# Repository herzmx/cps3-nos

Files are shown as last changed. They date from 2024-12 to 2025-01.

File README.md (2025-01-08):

# CPS3 NOS (NOR Open SIMM)

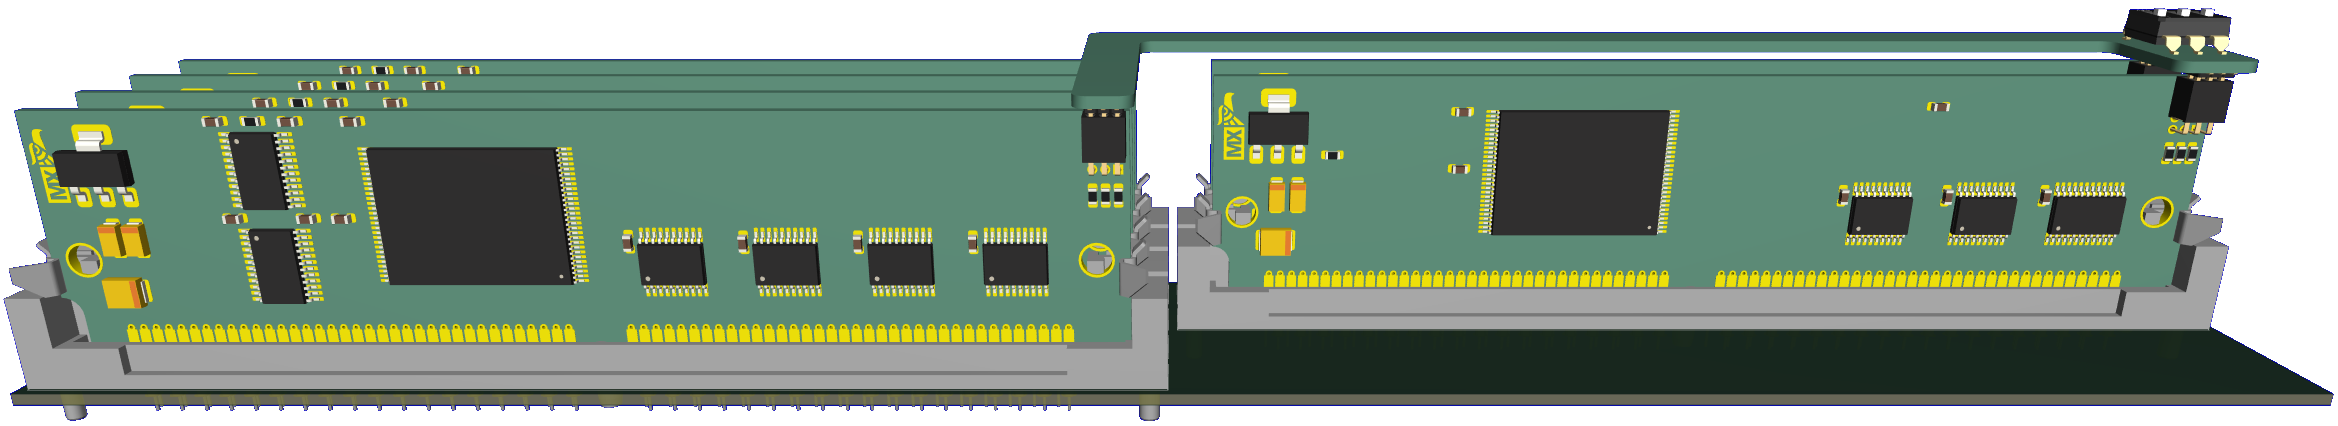
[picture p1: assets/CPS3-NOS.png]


CPS3 NOS is an alternative to the original SIMMs for CPS3; currently, the available options include clone SIMMs with old-stock FLASH memory and Ultra SIMMs by DS. 

The project shares similarities with UltraSIMM but is not based on it. Instead, it is a new implementation built using publicly available pinouts and CPS3 schematics from FPGA projects.

The initial design aimed to use SPANSION NOR FLASH as the main memory, but this proved unfeasible due to speed limitations causing significant instability. As a result, MICRON NOR FLASH was used instead. While this is the same type of memory used in UltraSIMM and shares its pinout, but it's not directly compatible with UltraSIMM/UltraBIOS setup, because it is an entirely separate implementation.

The primary purpose of this project is to provide an alternative to SIMMs for catridges with original keys and battery, addressing the risks involved when updating the BIOS using the [CPS3 SIMM/CARTRIDGE PORT ADAPTER for OSCR](https://github.com/herzmx/CPS3-OSCR-Adapter). This project is not intended to create a new multi-SIMM solution. Given this primary purpose, it is very likely that UltraSIMM would also works on catridges with original keys and battery, though I do not have access to one to confirm.

## Issue Detected on 128MB NOS Module

Issue is identified with the 128MB NOS module causing intermittent problems after extended use. This may impact performance in games.

If you’ve already sent files for a production release, we sincerely apologize for the inconvenience. At this time, I’m not entirely confident in the stability of this release.

The primary purpose of this project is extend the functionality of [CPS3 SIMM/CARTRIDGE PORT ADAPTER for OSCR](https://github.com/herzmx/CPS3-OSCR-Adapter). With this adapter, you gain exciting new possibilities for dumping cartridges or testing configurations.

Thank you for your understanding, and I apologize for any inconvenience this may have caused.

<video src="./assets/NOS-128-issue.mp4" width="320" height="240" controls></video>

## Assembly/Production  

Gerber, BOM, and POS files are provided in the `hw` directory. You can send them directly to a PCB fabrication company or assemble the boards yourself.  

When assembling, consider that the minimum pitch is **0.5mm**, and the footprint for capacitors and resistors is **0603**.

**Important!!!**, PCB tickness it's **1.2mm**

### 64MB SIMM  

For 64MB SIMMs, you can use the following parallel NOR FLASH memory chips:  

- **Micron MT28EW256/512/01G**  
- **Spansion S29256/512/GL01G** (use the 100ns speed version)  

### 128MB SIMM  

For 128MB SIMMs, only **Micron MT28EW01G** parallel NOR FLASH is supported. During development and testing, **Spansion** memory did not work as expected with bank switching on the 128MB SIMM.  

### Notes  

- Use only one type of SIMM when assembling a single **64MB SIMM**.  
- You can mix **Micron** and **Spansion** SIMMs if needed.  

## How to use

CPS3 can only handle four types of FLASH memory due to the instructions used for flashing new games through the system, these instructions are supported and coded in the BIOS.  

To make a new NOR FLASH memory compatible with CPS3, a BIOS patch is required.

### BIOS Patch

The **bios_patch.py** script allows you to apply patches to your current BIOS, adding compatibility for **SPANSION** and **MICRON** NOR FLASH.

For example, if you have a dump of *Street Fighter III 3rd Strike*, you can execute the following command to patch BIOS:

```bash
python bios_patch.py sfiii3_usa.29f400.u2 sfiii3
```

#### Compatibility Table

| Before patch | After patch |
|---|---|
| MXCI | MXCI |
| SHARP/INTEL  | SHARP/INTEL |
| HITACHI | SPANSION |
| MXIC | MICRON NOS/UltraSIMM |

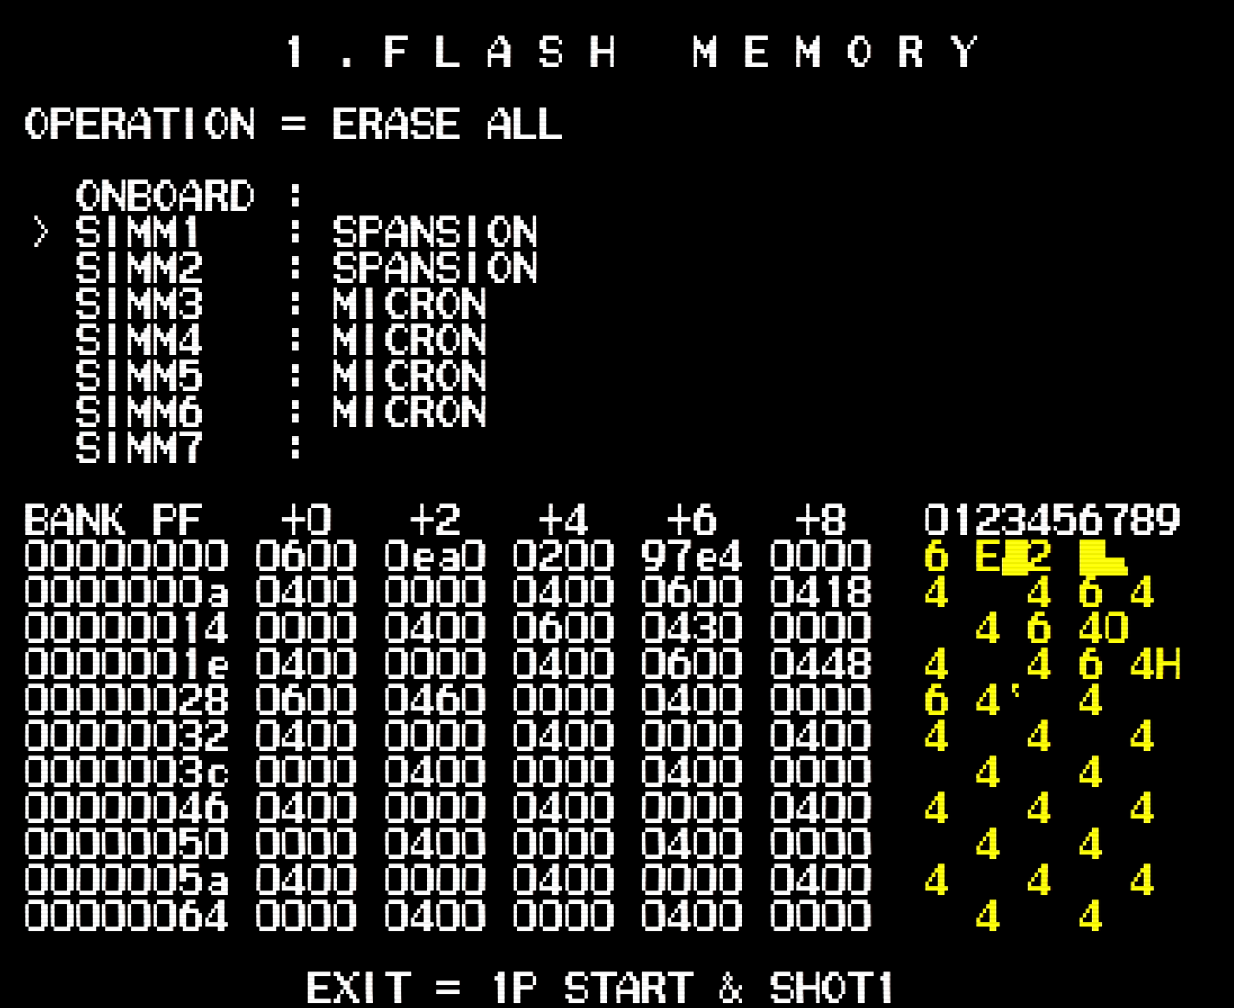
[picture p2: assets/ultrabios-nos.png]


### Flashing Your New BIOS

Once the patch is applied, it's time to flash your updated BIOS onto the cartridge. There are two main methods you can use:

1. **Using the [CPS3 SIMM/CARTRIDGE PORT ADAPTER for OSCR](https://github.com/herzmx/CPS3-OSCR-Adapter)**  
   - This method works for both alive and death cartridges.
   - **NOTE**: Use it at your own risk on alive cartridges!

2. **Traditional Method**  
   - Remove the 29F400 chip from the cartridge and flash it using a programmer.  
   - This method is only recommended for death cartridges.

Now your cartdrige it's compatible with NOS!

### R/W CPS3 NOS 

Currently, CPS3 NOS can only be programmed using the [CPS3 SIMM/CARTRIDGE PORT ADAPTER for OSCR](https://github.com/herzmx/CPS3-OSCR-Adapter).

#### Prepare your files 

- **Dump or copy**  your CD-ROM files and organize them into a directory. For example, for *Street Fighter III: 2nd Impact*, the directory structure should look like this:

	```
    CDROM
    └── SFIII2
        ├── 10
        ├── 20
        ├── 30
        ├── 31
        ├── 40
        ├── 41
        ├── 50
        ├── 51
        ├── 90
        ├── 91
        ├── 92
        └── 93
	```

- Concatenate files for each SIMM
	- For **128M SIMMs**, use files 3# to 6#. 
	- For **64M SIMMs**, use files 10 and 20.
	
	 Example (using a Unix terminal):
	 
	 ```bash
	 	cat WAZARD/10WZ SFIII/10NG SFIII2/10 JOJO/10JO SFIII3B/103S2 JOJOBA/10JB > NOS10

		cat WAZARD/10WZFix SFIII/10NG SFIII2/10 JOJO/10JO SFIII3B/103S2 JOJOBA/10JB > NOS10
		
		cat WAZARD/20WZ SFIII/20NG SFIII2/20 JOJO/20JO SFIII3B/203S2 JOJOBA/20JB > NOS20
		
		cat WAZARD/30WZ WAZARD/31WZ SFIII/30NG SFIII/31NG SFIII2/30 SFIII2/31 JOJO/30JO JOJO/31JO SFIII3B/303S2 SFIII3B/313S2 JOJOBA/30JB JOJOBA/31JB > NOS30
		
		cat WAZARD/40WZ WAZARD/41WZ SFIII/40NG SFIII/41NG SFIII2/40 SFIII2/41 JOJO/40JO JOJO/41JO SFIII3B/403S2 SFIII3B/413S2 JOJOBA/40JB JOJOBA/41JB > NOS40
		
		cat WAZARD/50WZ WAZARD/51WZ SFIII/50NG SFIII/51NG SFIII2/50 SFIII2/51 JOJO/50JO JOJO/51JO SFIII3B/503S2 SFIII3B/513S2 JOJOBA/50JB JOJOBA/51JB > NOS50
		
		cat WAZARD/60WZ WAZARD/61WZ SFIII/60NG SFIII/61NG SFIII2/60 SFIII2/61 JOJO/60JO JOJO/61JO SFIII3B/603S2 SFIII3B/613S2 JOJOBA/60JB JOJOBA/61JB > NOS60
	 ```
	 
**Important Notes**
 
- NOS supports up to 8 titles. When using this feature, you must fill all SIMM slots and space.
- For example, when working with *Street Fighter III: New Generation*, you can duplicate certain files to fill all space:
- Use `10` as `20` for SIMM 2.
- Use `50` four times for SIMM 5.
- Use `40` as `60 `for SIMM 6.
 	
| | 1 | 2 | 3 | 4 | 5 | 6 |
|---|---|---|---|---|---|---|
| Street Fighter III: New Generation | 64MBit | - | 128MBit | 128MBit | 32MBit  | - |
| Street Fighter III: New Generation (filled) | 64MBit | 64MBit | 128MBit | 128MBit | 128MBit | 128MBit |

Alternatively, you can use the **ds2nos.py** script to convert UltraSIMM files to NOS format.

#### Write NOS

The [CPS3 SIMM/CARTRIDGE PORT ADAPTER for OSCR](https://github.com/herzmx/CPS3-OSCR-Adapter) has designated slots for 64M and 128M SIMMs. Insert your NOS into the corresponding slot and connect the headers for additional addressing.

system
system

- Prepare your SD, copy NOS10* to NOS60* in root
- Use *Capcom System III* menu options to write files
- 128 MB

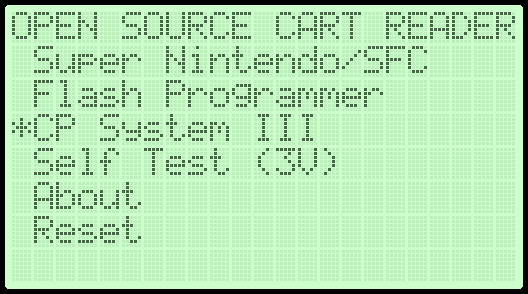
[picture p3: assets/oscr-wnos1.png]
	
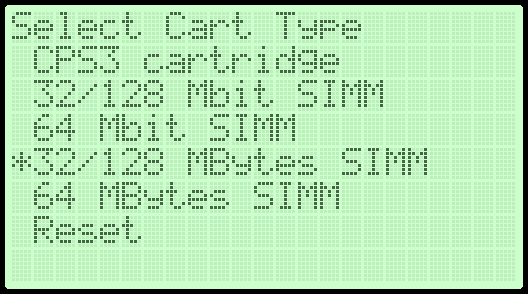
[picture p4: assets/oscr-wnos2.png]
	
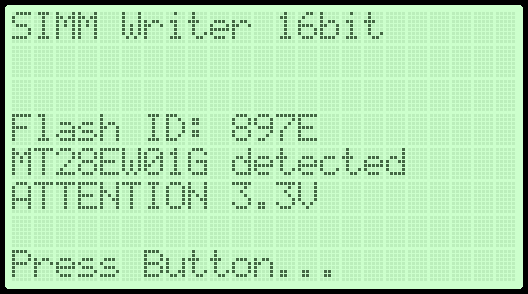
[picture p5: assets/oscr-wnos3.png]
	
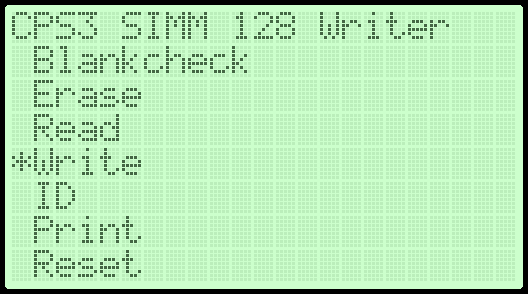
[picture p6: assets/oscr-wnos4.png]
	
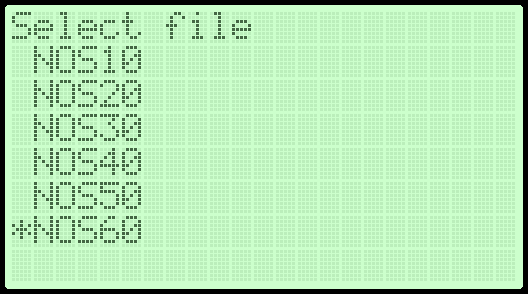
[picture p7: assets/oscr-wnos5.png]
	
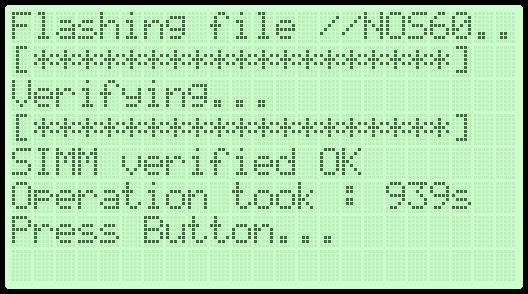
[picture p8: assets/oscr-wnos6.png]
	

- 64 MB

	system
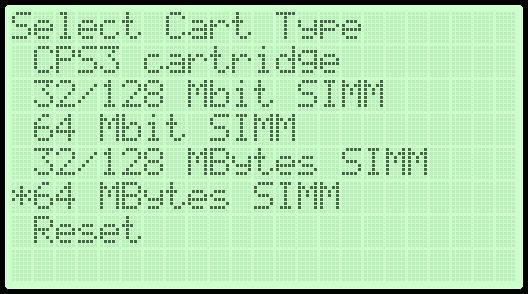
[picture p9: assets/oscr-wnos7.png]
	
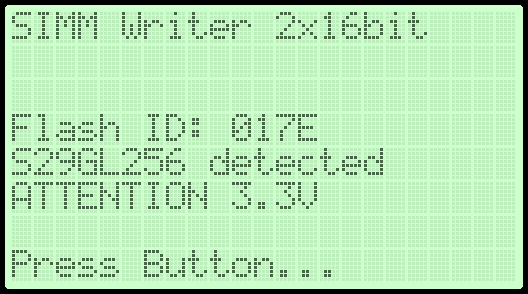
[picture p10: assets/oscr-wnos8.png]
	
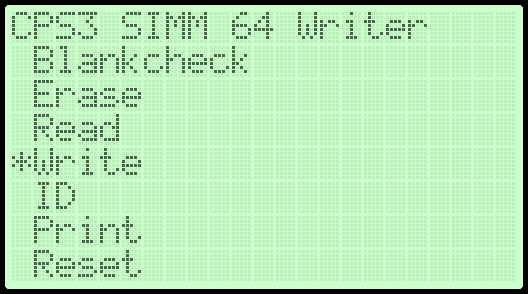
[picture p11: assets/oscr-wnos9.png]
	
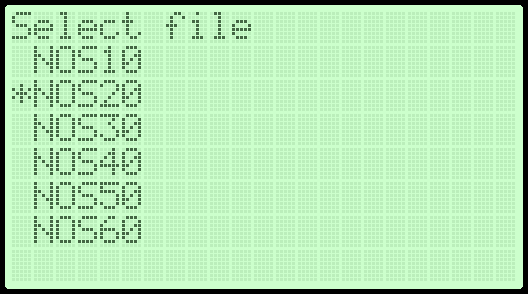
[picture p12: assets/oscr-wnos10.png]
	
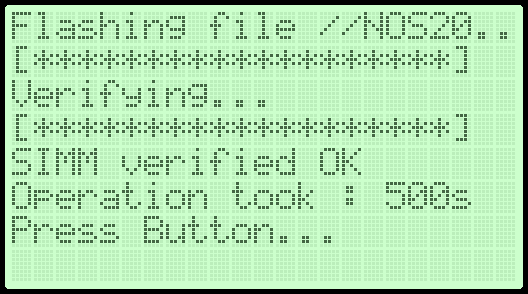
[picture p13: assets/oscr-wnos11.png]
	

### Install NOS on CPS3

- After writing all the NOS, install the SIMMs into the CPS3. It is recommended to label each SIMM to prevent any mix-ups in the future.

system
system

- Install the SW header to link all NOS if you plan to use more than one title.

system
system

### NOS SW Reference Table

| SW Config | |
|---|---|
| system | GAME 1 |
| system | GAME 2 |
| system | GAME 3 |
| system | GAME 4 |
| system | GAME 5 |
| system | GAME 6 |
| system | GAME 7 |
| system | GAME 8 |

## Disclaimer!!!

**I am not responsible for any damage to your CPS3 cartridges or system. At this time, it remains untested in live cartridges, so use it at your own risk!**

## License
<br />This work is licensed under a <a rel="license" href="http://creativecommons.org/licenses/by-nc-sa/4.0/">Creative Commons Attribution-NonCommercial-ShareAlike 4.0 International</a>. You are able to reusers to distribute, remix, adapt, and build upon the material in any medium or format for noncommercial purposes only, and only so long as attribution is given. If you remix, adapt, or build upon the material, you must license the modified material under identical terms.

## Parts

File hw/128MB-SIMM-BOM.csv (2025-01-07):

Comment | Designator | Footprint | LCSC
100uf | C1 | Capacitor_Tantalum_SMD:CP_EIA-3528-12_Kemet-T | C122271
10uf | C2,C3 | Capacitor_Tantalum_SMD:CP_EIA-3216-10_Kemet-I | C110052
100nf | C4,C5,C6,C7,C8,C9,C10,C11,C12,C13,C14 | Capacitor_SMD:C_0603_1608Metric | C14663
Conn_02x03_Odd_Even | J2 | Connector_PinSocket_1.27mm:PinSocket_2x03_P1.27mm_Horizontal | C2881889
10K | R1,R2,R3,R4,R5 | Resistor_SMD:R_0603_1608Metric | C98220
LM1117-3.3 | U1 | Package_TO_SOT_SMD:SOT-223-3_TabPin2 | C23984
74LVC4245A | U2,U3 | Package_SO:TSSOP-24_4.4x7.8mm_P0.65mm | C7859
S29GL01GS | U4 | Package_SO:TSOP-I-56_18.4x14mm_P0.5mm | C2064354
74LVC245A | U5,U6,U7,U8 | Package_SO:TSSOP-20_4.4x6.5mm_P0.65mm | C7848
74LS148 | U9 | Package_SO:SOIC-16_3.9x9.9mm_P1.27mm | C2674594

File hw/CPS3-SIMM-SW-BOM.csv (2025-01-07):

Comment | Designator | Footprint | LCSC
Conn_02x03_Odd_Even | J1,J2,J3,J4,J5,J6 | Connector_PinHeader_1.27mm:PinHeader_2x03_P1.27mm_Vertical_SMD | C5160759
SW_DIP_x03 | SW1 | CPS3:SW-SMD_6P-L8.6-W6.2-P2.54-LS9.8 | C319040

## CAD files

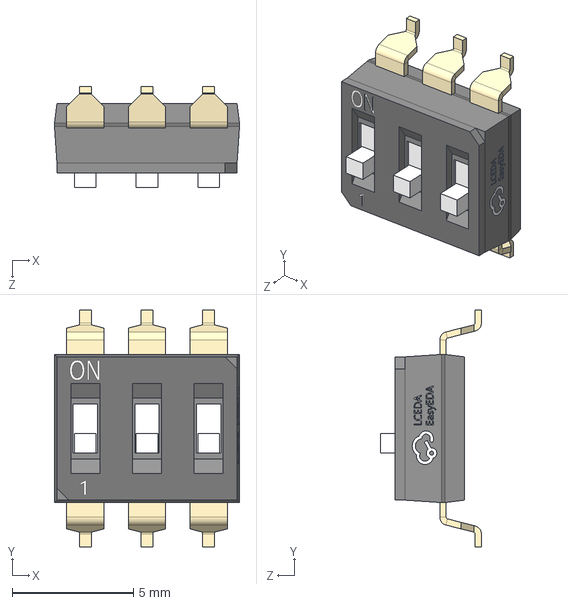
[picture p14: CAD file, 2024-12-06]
src/3D/SW-SMD_6P-L7.6-W6.1-H4.2-P2.54-LS9.8.step
7.62 x 9.76 x 4.15 mm

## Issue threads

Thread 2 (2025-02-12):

Where are the files for the OSCR?

sh00tthec0re, 2025-02-12:
I've built your CPS3 adapter and am getting ready to try it with my Open Source Cartridge Reader, but I'm not seeing the files for it in the repository. Your instructions say "Prepare your SD, copy NOS10* to NOS60* in root" but I'm not seeing files in the repository that match that description.

dreadzone92, 2025-02-12:
Hi, I guess your are looking for this : https://github.com/herzmx/cartreader/tree/cps3

herzmx, 2025-02-12:
@sh00tthec0re, NOS10* to NOS60* it's only for NOS, and it's generated with your game dumps or by ds2nos.py that convert UltraSIMM contents to NOS, don't provide any game dump files here.

If you build https://github.com/herzmx/CPS3-OSCR-Adapter, you need to build ( https://github.com/herzmx/cartreader/tree/cps3 and put contents of https://github.com/herzmx/cartreader/tree/cps3/sd in root of SD.

You can follow instructions to Flash firmware https://github.com/sanni/cartreader/wiki/How-to-flash-the-Arduino, only open https://github.com/herzmx/cartreader/blob/cps3/Cart_Reader/Cart_Reader.ino or use provided hex files with [AVRDUDESS](https://github.com/ZakKemble/AVRDUDESS)

[Cart_Reader.zip](https://github.com/user-attachments/files/18770566/Cart_Reader.zip)

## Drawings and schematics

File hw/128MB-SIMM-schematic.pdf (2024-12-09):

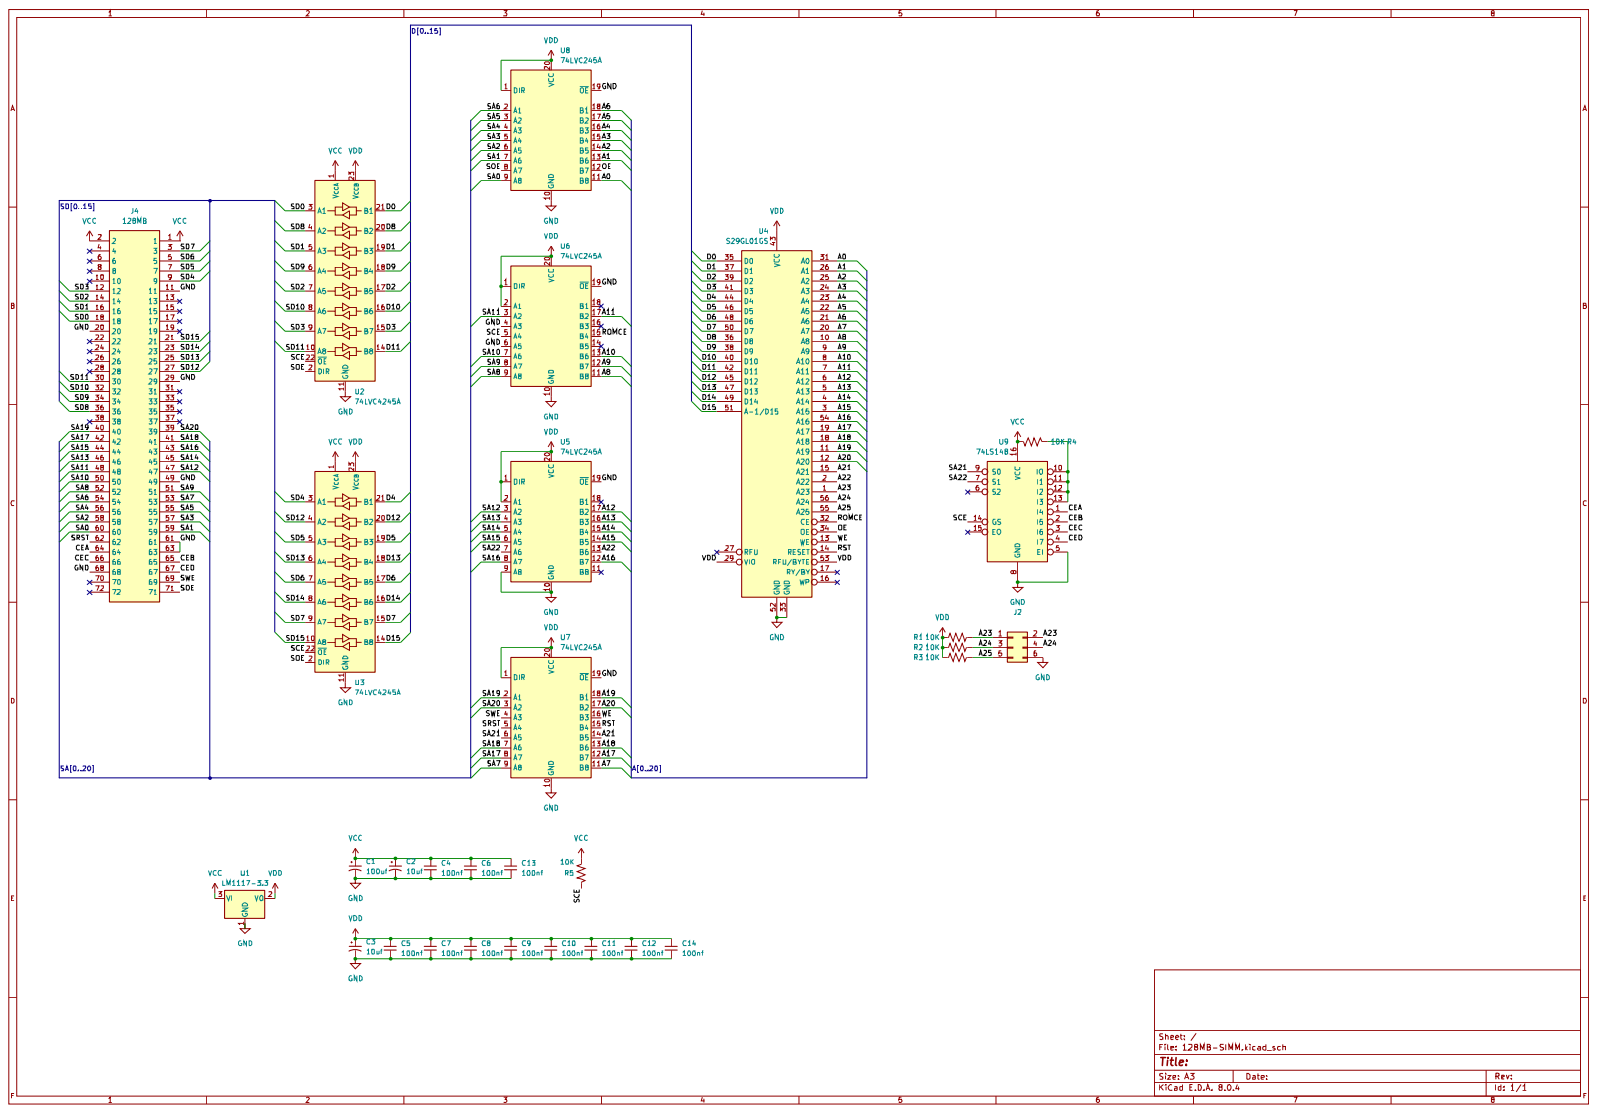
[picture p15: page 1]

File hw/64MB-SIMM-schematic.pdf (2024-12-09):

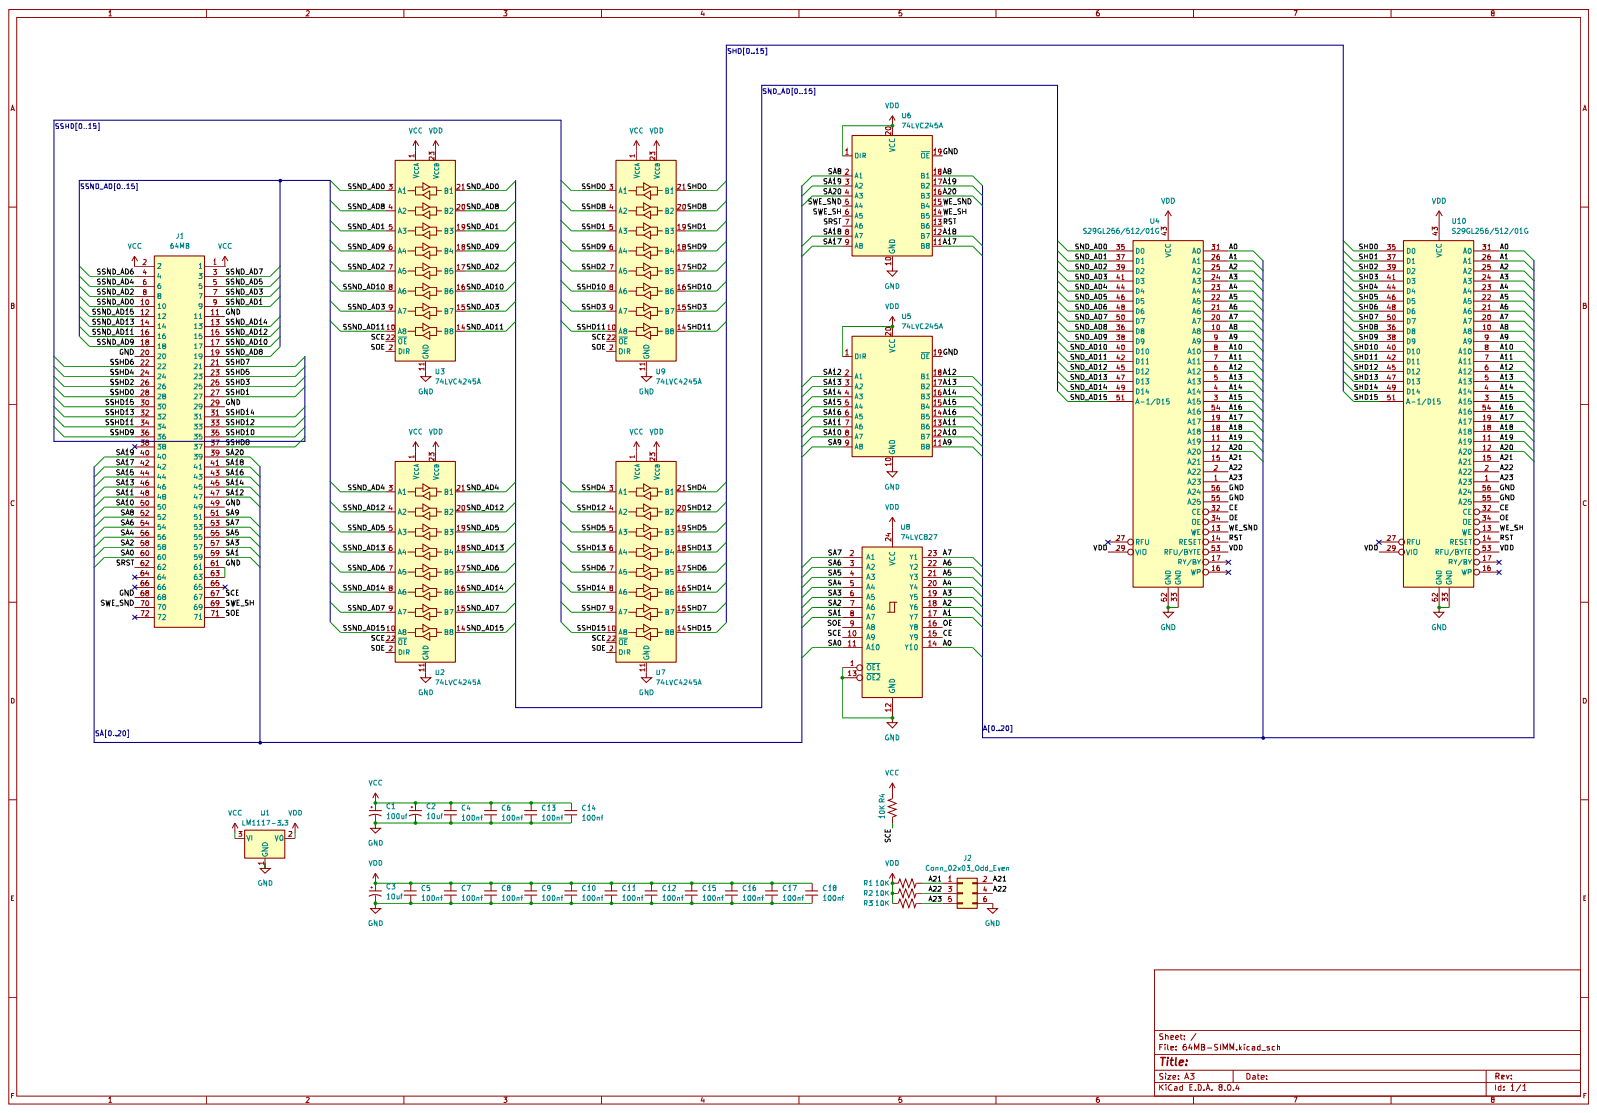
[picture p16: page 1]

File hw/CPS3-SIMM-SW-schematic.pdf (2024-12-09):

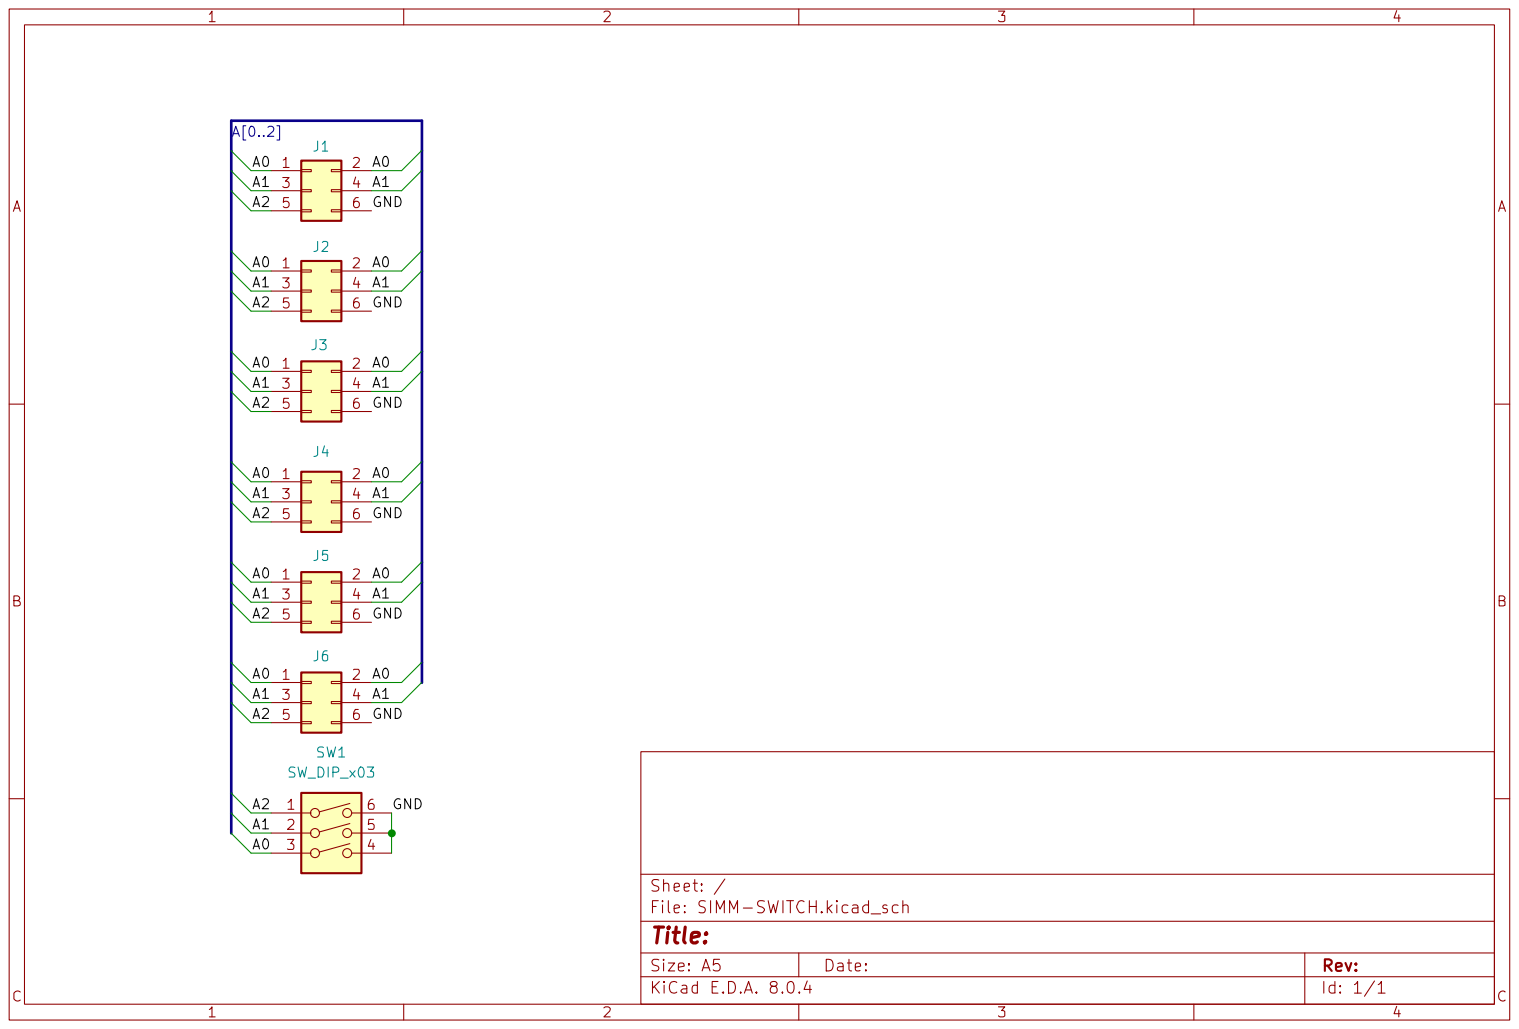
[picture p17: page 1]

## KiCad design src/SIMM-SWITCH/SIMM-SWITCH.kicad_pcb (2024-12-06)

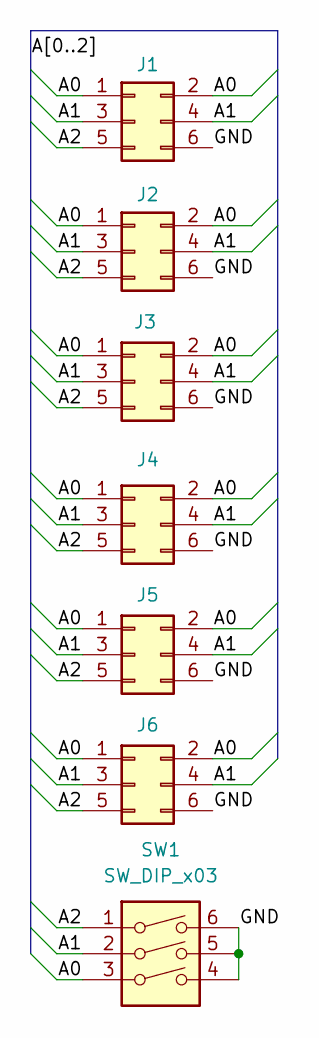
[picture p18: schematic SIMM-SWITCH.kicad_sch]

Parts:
J1, J2, J3, J4, J5, J6: Conn_02x03_Odd_Even; PinHeader_2x03_P1.27mm_Vertical_SMD; LCSC C2881908
SW1: SW_DIP_x03; SW-SMD_6P-L8.6-W6.2-P2.54-LS9.8; LCSC C319040

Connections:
/A0: J1.1, J1.2, J2.1, J2.2, J3.1, J3.2, J4.1, J4.2, J5.1, J5.2, J6.1, J6.2, SW1.3
/A1: J1.3, J1.4, J2.3, J2.4, J3.3, J3.4, J4.3, J4.4, J5.3, J5.4, J6.3, J6.4, SW1.2
/A2: J1.5, J2.5, J3.5, J4.5, J5.5, J6.5, SW1.1
/GND: J1.6, J2.6, J3.6, J4.6, J5.6, J6.6, SW1.4, SW1.5, SW1.6

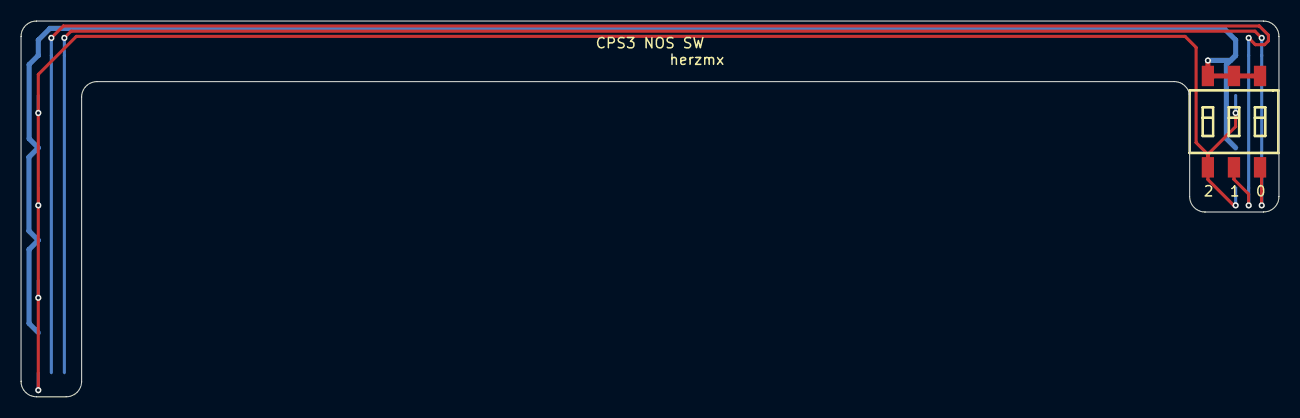
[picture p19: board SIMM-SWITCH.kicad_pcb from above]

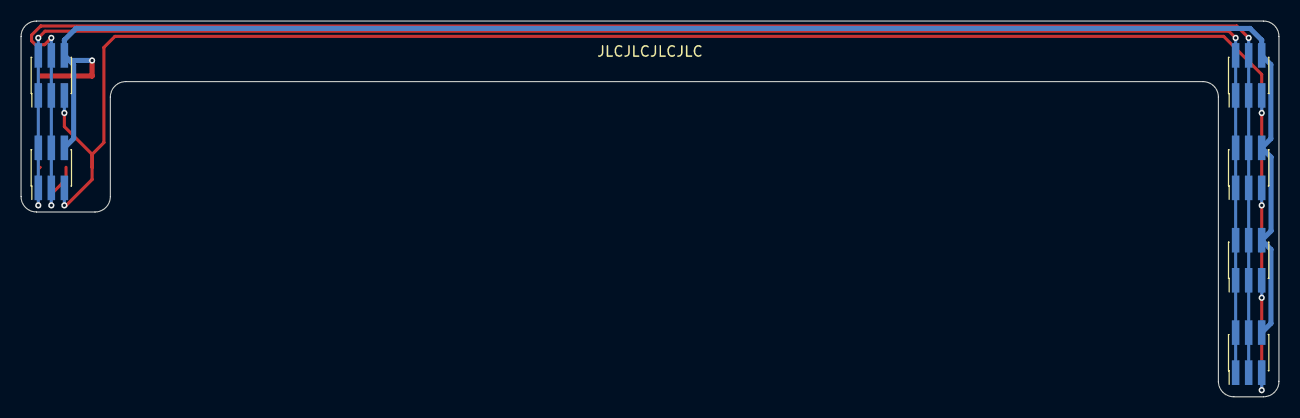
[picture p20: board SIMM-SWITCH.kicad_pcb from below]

Board: 2 copper layers, 122.5 x 36.6 mm, 7 parts (6 on the bottom side), 4 nets.

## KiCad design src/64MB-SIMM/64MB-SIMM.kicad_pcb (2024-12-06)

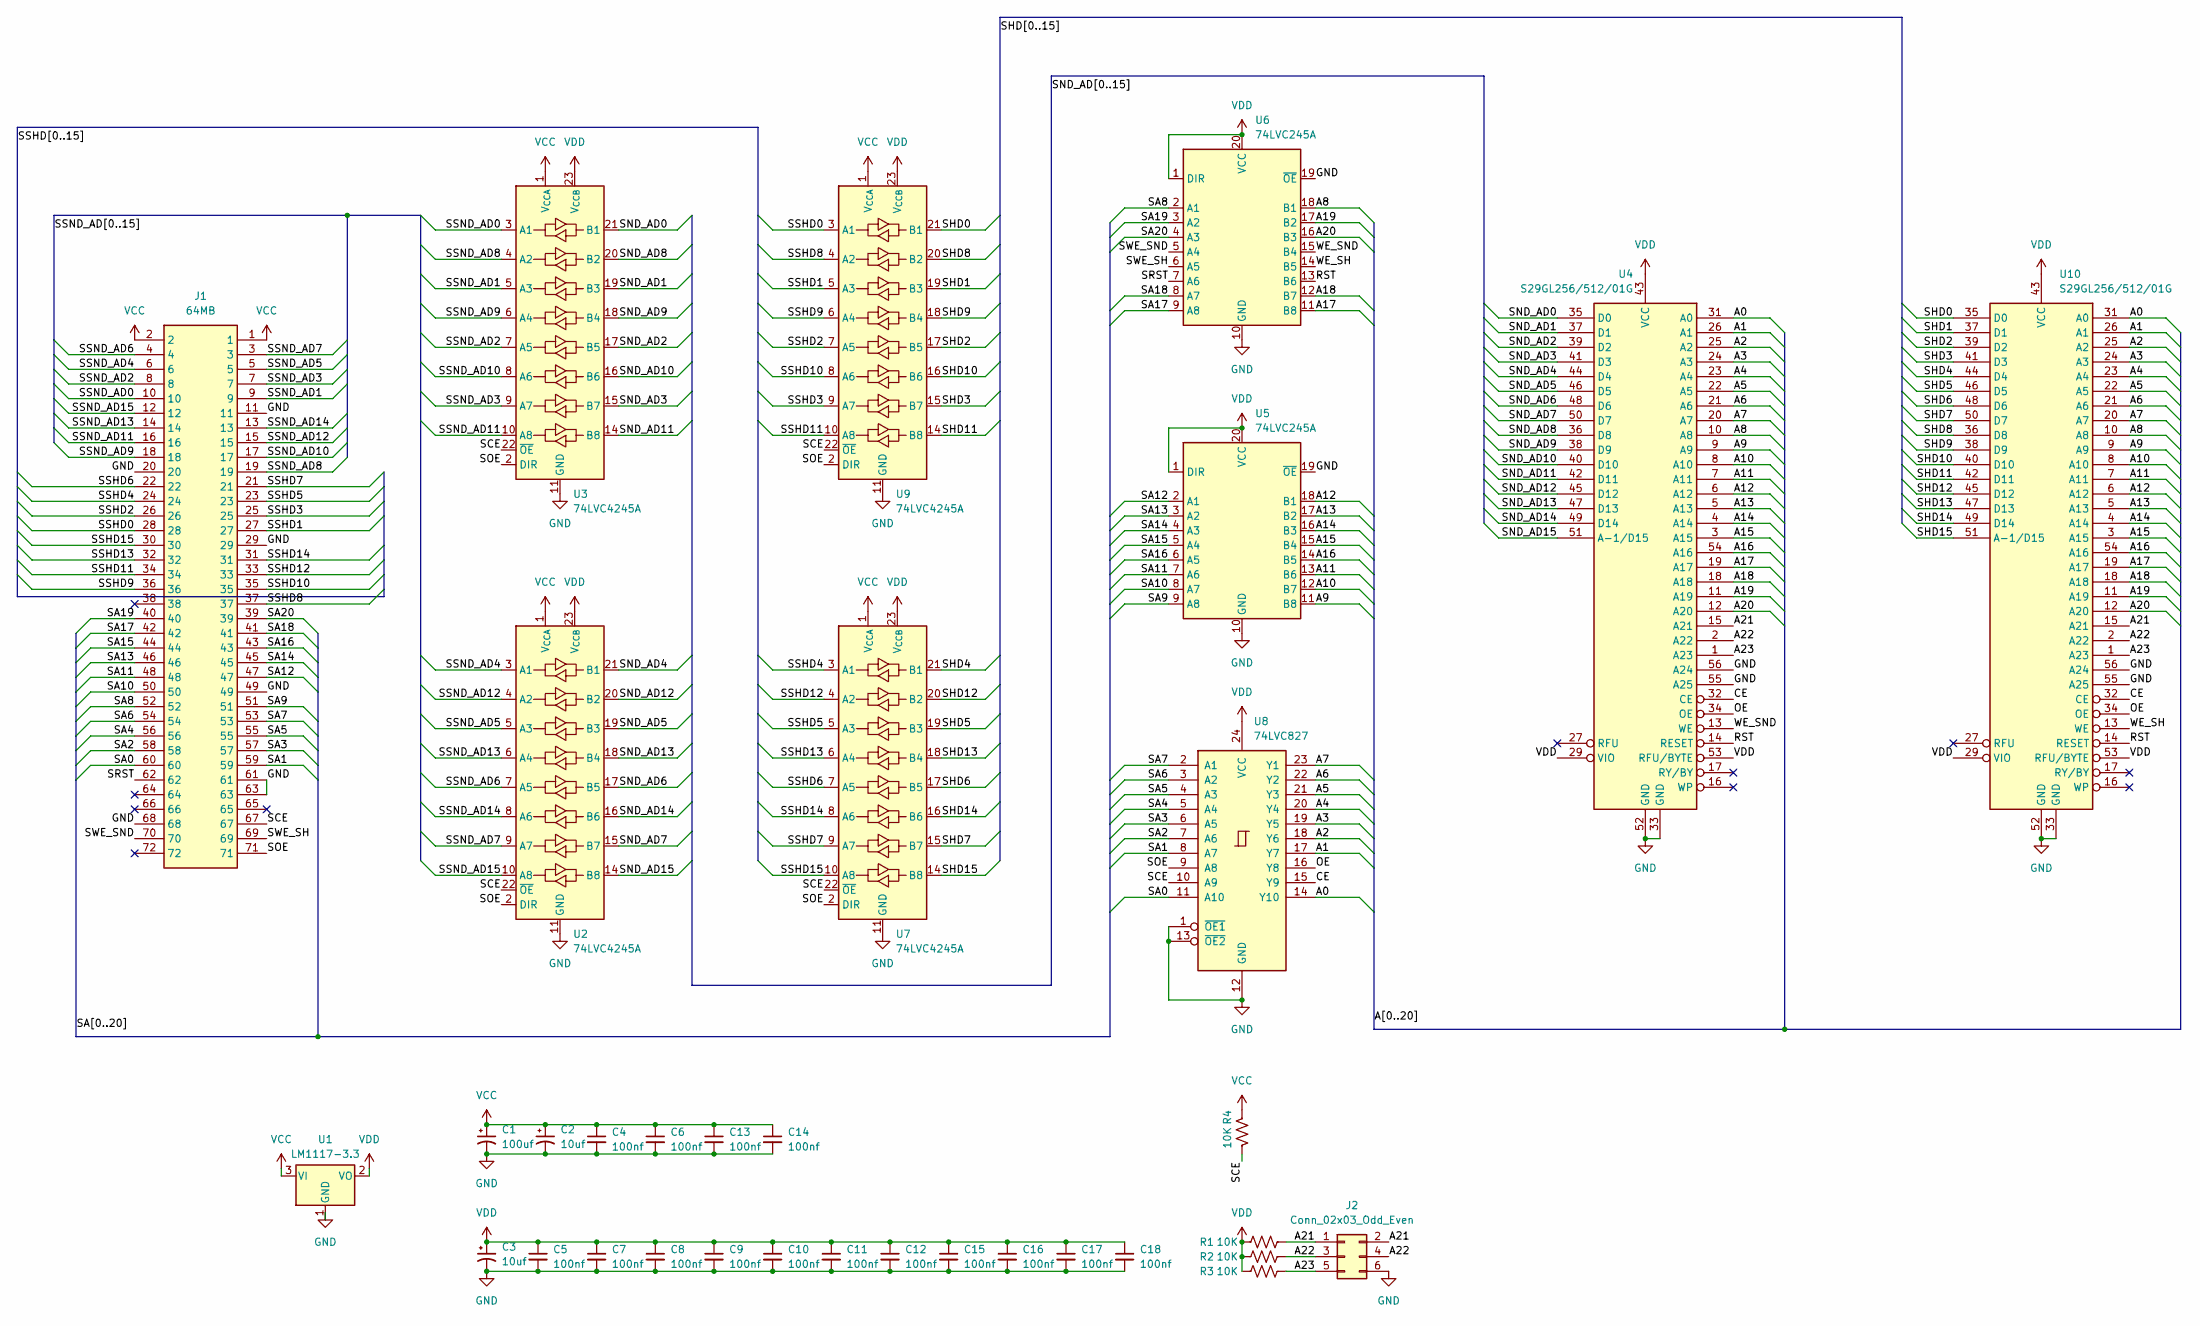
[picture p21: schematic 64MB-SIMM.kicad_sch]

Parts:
C1: 100uf; CP_EIA-3528-12_Kemet-T; LCSC C122271
C2, C3: 10uf; CP_EIA-3216-10_Kemet-I; LCSC C110052
C4, C5, C6, C7, C8, C9, C10, C11, C12, C13, C14, C15, C16, C17, C18: 100nf; C_0603_1608Metric; LCSC C14663
J1: 64MB; SIMM_EDGE; Manufacturer_Part_Number 5822030-3; Mouser Part Number 571-5822030-3
J2: Conn_02x03_Odd_Even; PinSocket_2x03_P1.27mm_Horizontal; LCSC C2881889
R1, R2, R3, R4: 10K; R_0603_1608Metric; LCSC C98220
U1: LM1117-3.3; SOT-223-3_TabPin2; LCSC C23984
U2, U3, U7, U9: 74LVC4245A; TSSOP-24_4.4x7.8mm_P0.65mm; LCSC C7859
U4, U10: S29GL256/512/01G; TSOP-I-56_18.4x14mm_P0.5mm; LCSC C598853
U5, U6: 74LVC245A; TSSOP-20_4.4x6.5mm_P0.65mm; LCSC C7848
U8: 74LVC827; TSSOP-24_4.4x7.8mm_P0.65mm; LCSC C2652112

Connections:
/A0: U4.31 (A0), U8.14 (Y10), U10.31 (A0)
/A1: U4.26 (A1), U8.17 (Y7), U10.26 (A1)
/A2: U4.25 (A2), U8.18 (Y6), U10.25 (A2)
/A3: U4.24 (A3), U8.19 (Y5), U10.24 (A3)
/A4: U4.23 (A4), U8.20 (Y4), U10.23 (A4)
/A5: U4.22 (A5), U8.21 (Y3), U10.22 (A5)
/A6: U4.21 (A6), U8.22 (Y2), U10.21 (A6)
/A7: U4.20 (A7), U8.23 (Y1), U10.20 (A7)
/A8: U4.10 (A8), U6.18 (B1), U10.10 (A8)
/A9: U4.9 (A9), U5.11 (B8), U10.9 (A9)
/A10: U4.8 (A10), U5.12 (B7), U10.8 (A10)
/A11: U4.7 (A11), U5.13 (B6), U10.7 (A11)
/A12: U4.6 (A12), U5.18 (B1), U10.6 (A12)
/A13: U4.5 (A13), U5.17 (B2), U10.5 (A13)
/A14: U4.4 (A14), U5.16 (B3), U10.4 (A14)
/A15: U4.3 (A15), U5.15 (B4), U10.3 (A15)
/A16: U4.54 (A16), U5.14 (B5), U10.54 (A16)
/A17: U4.19 (A17), U6.11 (B8), U10.19 (A17)
/A18: U4.18 (A18), U6.12 (B7), U10.18 (A18)
/A19: U4.11 (A19), U6.17 (B2), U10.11 (A19)
/A20: U4.12 (A20), U6.16 (B3), U10.12 (A20)
/A21: J2.1, J2.2, R1.2, U4.15 (A21), U10.15 (A21)
/A22: J2.3, J2.4, R2.2, U4.2 (A22), U10.2 (A22)
/A23: J2.5, R3.2, U4.1 (A23), U10.1 (A23)
/CE: U4.32 (CE), U8.15 (Y9), U10.32 (CE)
/OE: U4.34 (OE), U8.16 (Y8), U10.34 (OE)
/RST: U4.14 (RESET), U6.13 (B6), U10.14 (RESET)
/SA0: J1.60, U8.11 (A10)
/SA1: J1.59, U8.8 (A7)
/SA2: J1.58, U8.7 (A6)
/SA3: J1.57, U8.6 (A5)
/SA4: J1.56, U8.5 (A4)
/SA5: J1.55, U8.4 (A3)
/SA6: J1.54, U8.3 (A2)
/SA7: J1.53, U8.2 (A1)
/SA8: J1.52, U6.2 (A1)
/SA9: J1.51, U5.9 (A8)
/SA10: J1.50, U5.8 (A7)
/SA11: J1.48, U5.7 (A6)
/SA12: J1.47, U5.2 (A1)
/SA13: J1.46, U5.3 (A2)
/SA14: J1.45, U5.4 (A3)
/SA15: J1.44, U5.5 (A4)
/SA16: J1.43, U5.6 (A5)
/SA17: J1.42, U6.9 (A8)
/SA18: J1.41, U6.8 (A7)
/SA19: J1.40, U6.3 (A2)
/SA20: J1.39, U6.4 (A3)
/SCE: J1.67, R4.2, U2.22 (~OE), U3.22 (~OE), U7.22 (~OE), U8.10 (A9), U9.22 (~OE)
/SHD0: U9.21 (B1), U10.35 (D0)
/SHD1: U9.19 (B3), U10.37 (D1)
/SHD2: U9.17 (B5), U10.39 (D2)
/SHD3: U9.15 (B7), U10.41 (D3)
/SHD4: U7.21 (B1), U10.44 (D4)
/SHD5: U7.19 (B3), U10.46 (D5)
/SHD6: U7.17 (B5), U10.48 (D6)
/SHD7: U7.15 (B7), U10.50 (D7)
/SHD8: U9.20 (B2), U10.36 (D8)
/SHD9: U9.18 (B4), U10.38 (D9)
/SHD10: U9.16 (B6), U10.40 (D10)
/SHD11: U9.14 (B8), U10.42 (D11)
/SHD12: U7.20 (B2), U10.45 (D12)
/SHD13: U7.18 (B4), U10.47 (D13)
/SHD14: U7.16 (B6), U10.49 (D14)
/SHD15: U7.14 (B8), U10.51 (A-1/D15)
/SND_AD0: U3.21 (B1), U4.35 (D0)
/SND_AD1: U3.19 (B3), U4.37 (D1)
/SND_AD2: U3.17 (B5), U4.39 (D2)
/SND_AD3: U3.15 (B7), U4.41 (D3)
/SND_AD4: U2.21 (B1), U4.44 (D4)
/SND_AD5: U2.19 (B3), U4.46 (D5)
/SND_AD6: U2.17 (B5), U4.48 (D6)
/SND_AD7: U2.15 (B7), U4.50 (D7)
/SND_AD8: U3.20 (B2), U4.36 (D8)
/SND_AD9: U3.18 (B4), U4.38 (D9)
/SND_AD10: U3.16 (B6), U4.40 (D10)
/SND_AD11: U3.14 (B8), U4.42 (D11)
/SND_AD12: U2.20 (B2), U4.45 (D12)
/SND_AD13: U2.18 (B4), U4.47 (D13)
/SND_AD14: U2.16 (B6), U4.49 (D14)
/SND_AD15: U2.14 (B8), U4.51 (A-1/D15)
/SOE: J1.71, U2.2 (DIR), U3.2 (DIR), U7.2 (DIR), U8.9 (A8), U9.2 (DIR)
/SRST: J1.62, U6.7 (A6)
/SSHD0: J1.28, U9.3 (A1)
/SSHD1: J1.27, U9.5 (A3)
/SSHD2: J1.26, U9.7 (A5)
/SSHD3: J1.25, U9.9 (A7)
/SSHD4: J1.24, U7.3 (A1)
/SSHD5: J1.23, U7.5 (A3)
/SSHD6: J1.22, U7.7 (A5)
/SSHD7: J1.21, U7.9 (A7)
/SSHD8: J1.37, U9.4 (A2)
/SSHD9: J1.36, U9.6 (A4)
/SSHD10: J1.35, U9.8 (A6)
/SSHD11: J1.34, U9.10 (A8)
/SSHD12: J1.33, U7.4 (A2)
/SSHD13: J1.32, U7.6 (A4)
/SSHD14: J1.31, U7.8 (A6)
/SSHD15: J1.30, U7.10 (A8)
/SSND_AD0: J1.10, U3.3 (A1)
/SSND_AD1: J1.9, U3.5 (A3)
/SSND_AD2: J1.8, U3.7 (A5)
/SSND_AD3: J1.7, U3.9 (A7)
/SSND_AD4: J1.6, U2.3 (A1)
/SSND_AD5: J1.5, U2.5 (A3)
/SSND_AD6: J1.4, U2.7 (A5)
/SSND_AD7: J1.3, U2.9 (A7)
/SSND_AD8: J1.19, U3.4 (A2)
/SSND_AD9: J1.18, U3.6 (A4)
/SSND_AD10: J1.17, U3.8 (A6)
/SSND_AD11: J1.16, U3.10 (A8)
/SSND_AD12: J1.15, U2.4 (A2)
/SSND_AD13: J1.14, U2.6 (A4)
/SSND_AD14: J1.13, U2.8 (A6)
/SSND_AD15: J1.12, U2.10 (A8)
/SWE_SH: J1.69, U6.6 (A5)
/SWE_SND: J1.70, U6.5 (A4)
/WE_SH: U6.14 (B5), U10.13 (WE)
/WE_SND: U4.13 (WE), U6.15 (B4)
GND: C1.2, C2.2, C3.2, C4.2, C5.2, C6.2, C7.2, C8.2, C9.2, C10.2, C11.2, C12.2, C13.2, C14.2, C15.2, C16.2, C17.2, C18.2, J1.11, J1.20, J1.29, J1.49, J1.61, J1.63, J1.68, J2.6, U1.1 (GND), U2.11 (GND), U2.12 (GND), U2.13 (GND), U3.11 (GND), U3.12 (GND), U3.13 (GND), U4.33 (GND), U4.52 (GND), U4.55 (A25), U4.56 (A24), U5.10 (GND), U5.19 (~OE), U6.10 (GND), U6.19 (~OE), U7.11 (GND), U7.12 (GND), U7.13 (GND), U8.1 (~OE1), U8.12 (GND), U8.13 (~OE2), U9.11 (GND), U9.12 (GND), U9.13 (GND), U10.33 (GND), U10.52 (GND), U10.55 (A25), U10.56 (A24)
VCC: C1.1, C2.1, C4.1, C6.1, C13.1, C14.1, J1.1, J1.2, R4.1, U1.3 (VI), U2.1 (V_{CCA}), U3.1 (V_{CCA}), U7.1 (V_{CCA}), U9.1 (V_{CCA})
VDD: C3.1, C5.1, C7.1, C8.1, C9.1, C10.1, C11.1, C12.1, C15.1, C16.1, C17.1, C18.1, R1.1, R2.1, R3.1, U1.2 (VO), U2.23 (V_{CCB}), U2.24 (V_{CCB}), U3.23 (V_{CCB}), U3.24 (V_{CCB}), U4.29 (VIO), U4.43 (VCC), U4.53 (RFU/BYTE), U5.1 (DIR), U5.20 (VCC), U6.1 (DIR), U6.20 (VCC), U7.23 (V_{CCB}), U7.24 (V_{CCB}), U8.24 (VCC), U9.23 (V_{CCB}), U9.24 (V_{CCB}), U10.29 (VIO), U10.43 (VCC), U10.53 (RFU/BYTE)

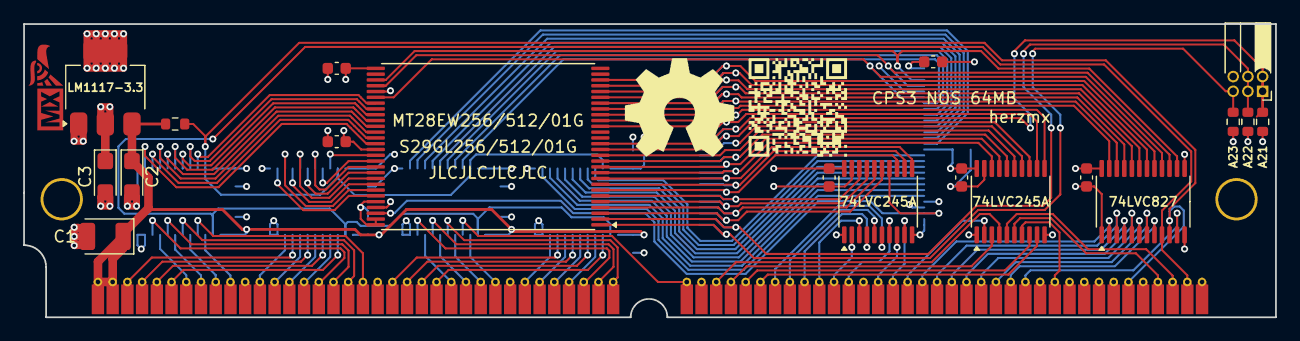
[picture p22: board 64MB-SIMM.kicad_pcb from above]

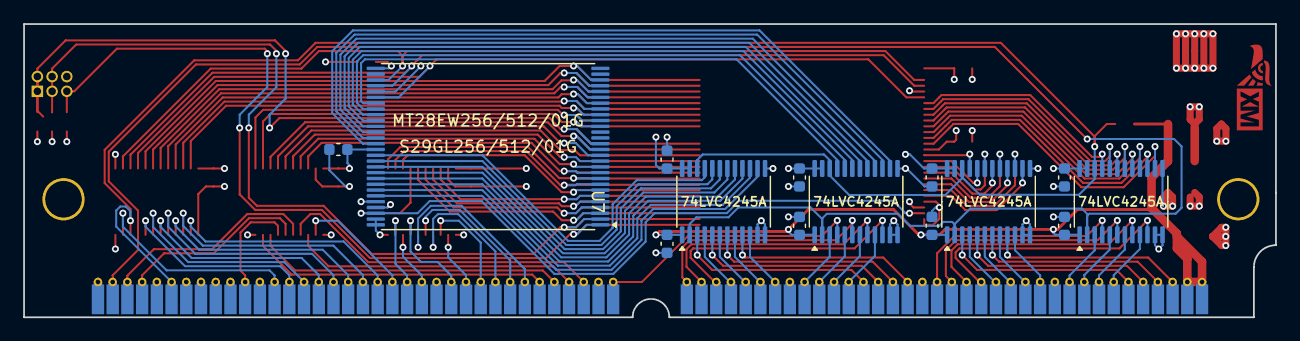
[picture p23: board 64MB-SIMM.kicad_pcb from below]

Board: 4 copper layers, 108.0 x 25.3 mm, 34 parts (15 on the bottom side), 122 nets.

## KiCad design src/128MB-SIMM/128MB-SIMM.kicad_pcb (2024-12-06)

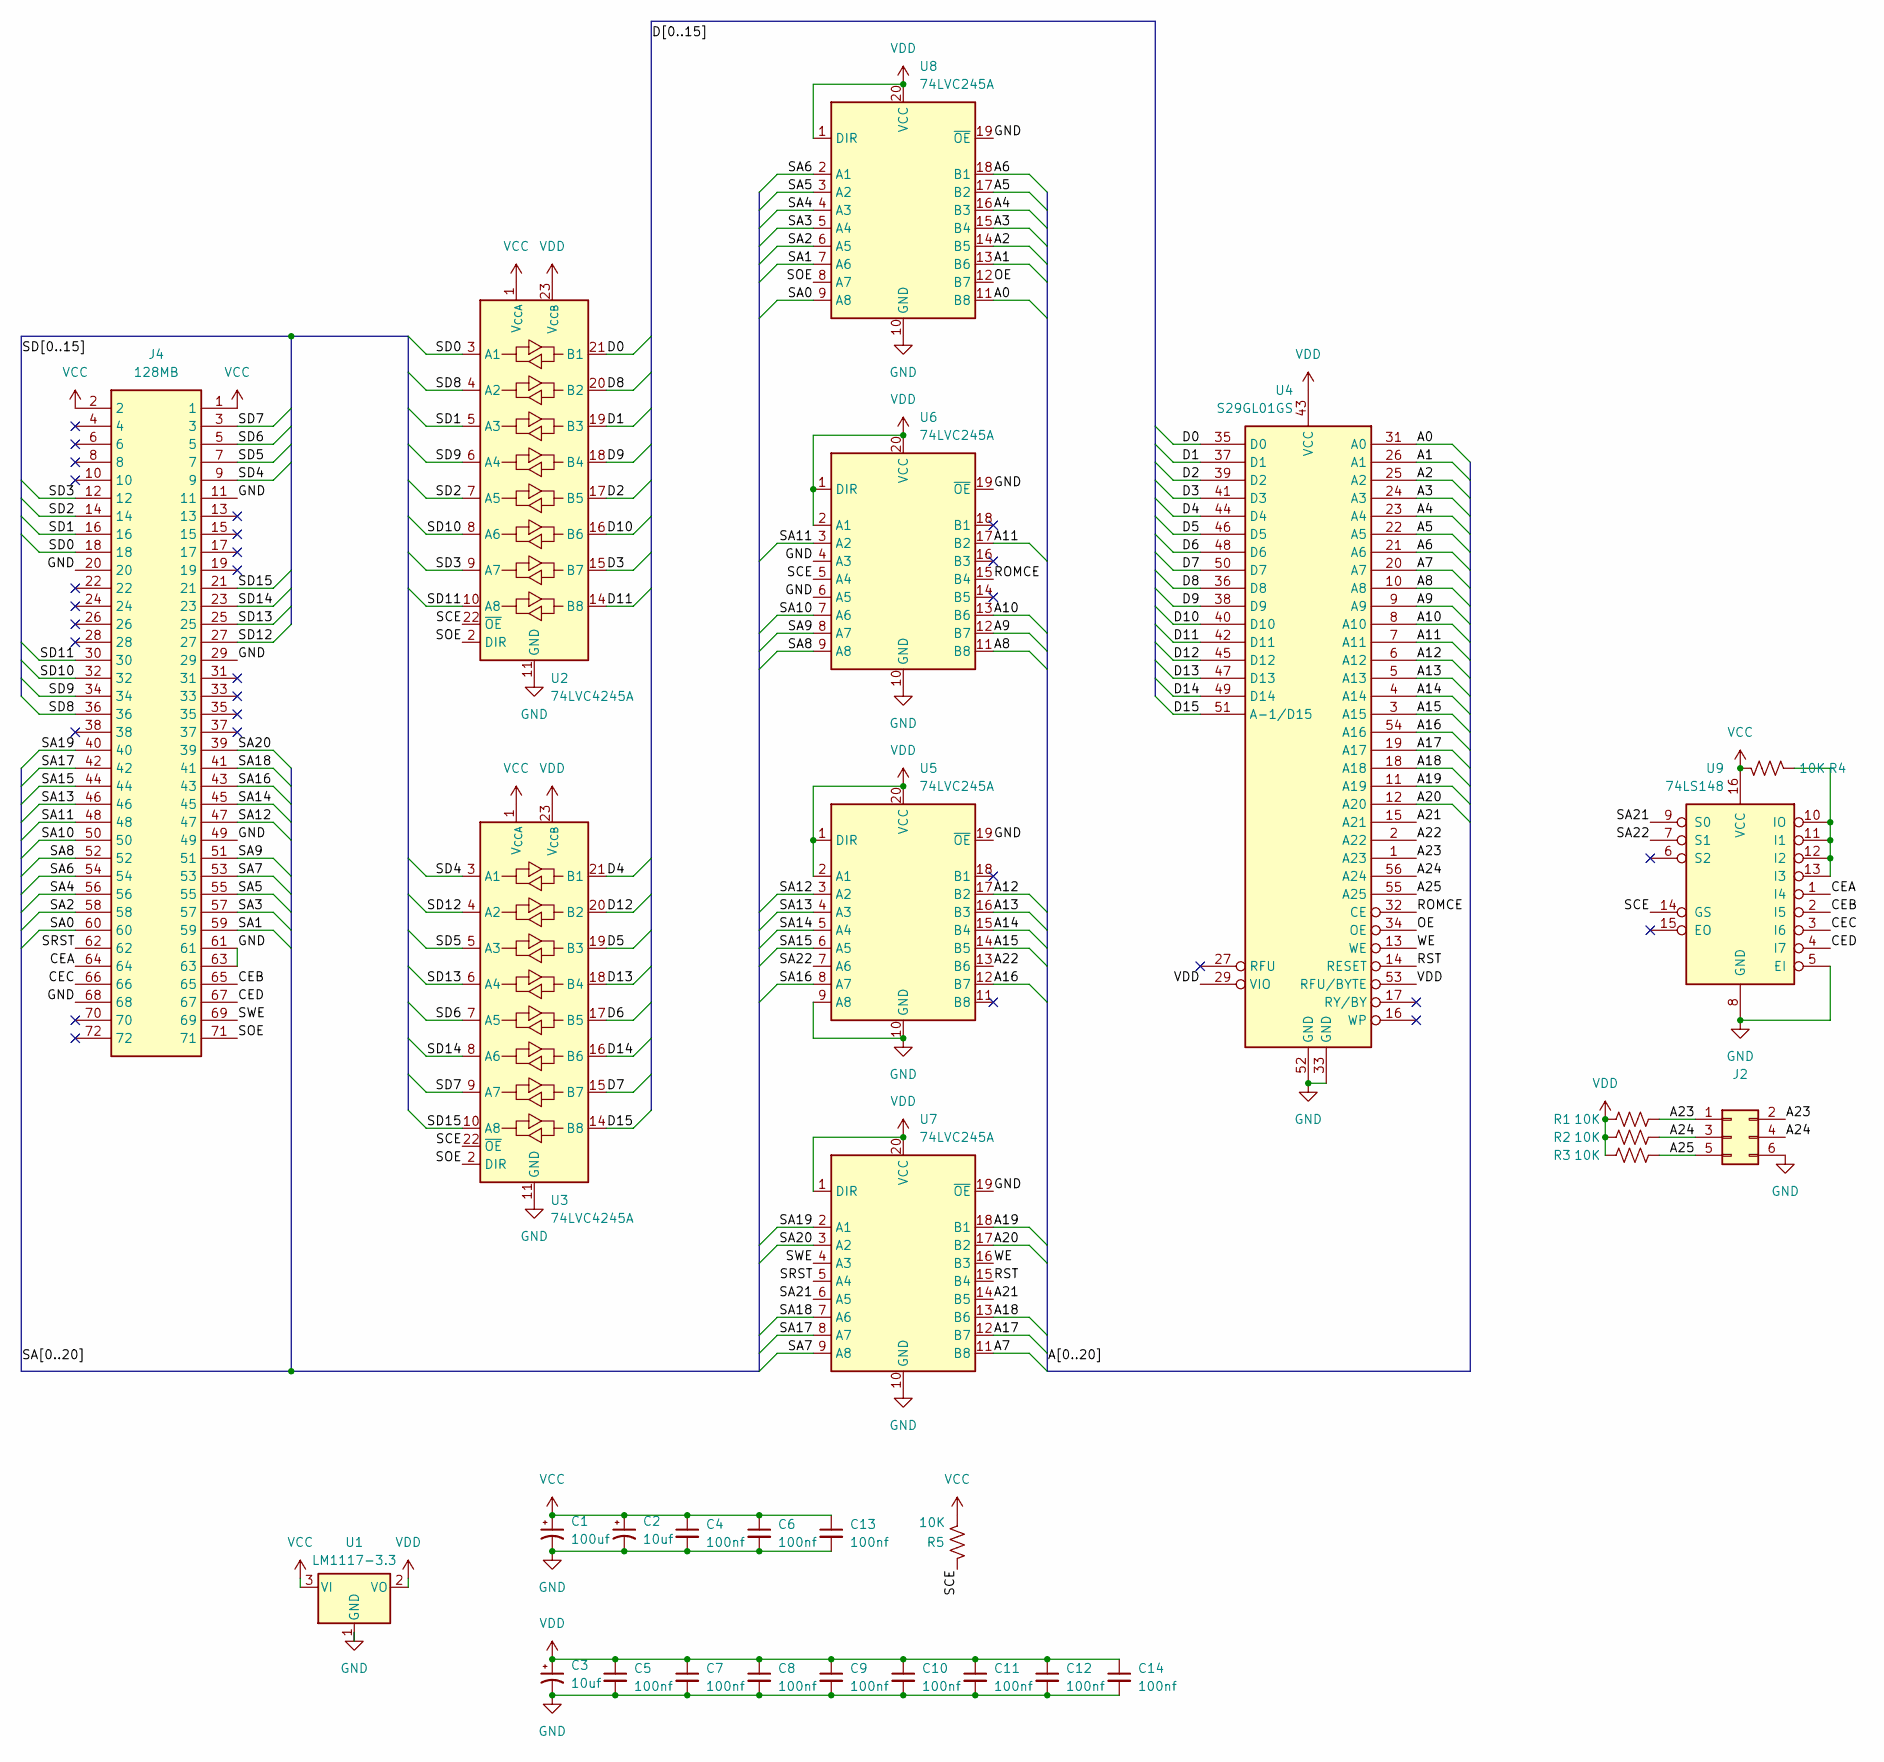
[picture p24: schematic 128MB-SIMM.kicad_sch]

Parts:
C1: 100uf; CP_EIA-3528-12_Kemet-T; LCSC C122271
C2, C3: 10uf; CP_EIA-3216-10_Kemet-I; LCSC C110052
C4, C5, C6, C7, C8, C9, C10, C11, C12, C13, C14: 100nf; C_0603_1608Metric; LCSC C14663
J2: Conn_02x03_Odd_Even; PinSocket_2x03_P1.27mm_Horizontal; LCSC C2881889
J4: 128MB; SIMM_EDGE; Manufacturer_Part_Number 5822030-3; Mouser Part Number 571-5822030-3
R1, R2, R3, R4, R5: 10K; R_0603_1608Metric; LCSC C98220
U1: LM1117-3.3; SOT-223-3_TabPin2; LCSC C23984
U2, U3: 74LVC4245A; TSSOP-24_4.4x7.8mm_P0.65mm; LCSC C7859
U4: S29GL01GS; TSOP-I-56_18.4x14mm_P0.5mm; LCSC C2064354
U5, U6, U7, U8: 74LVC245A; TSSOP-20_4.4x6.5mm_P0.65mm; LCSC C7848
U9: 74LS148; SOIC-16_3.9x9.9mm_P1.27mm; LCSC C2674594

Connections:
/A0: U4.31 (A0), U8.11 (B8)
/A1: U4.26 (A1), U8.13 (B6)
/A2: U4.25 (A2), U8.14 (B5)
/A3: U4.24 (A3), U8.15 (B4)
/A4: U4.23 (A4), U8.16 (B3)
/A5: U4.22 (A5), U8.17 (B2)
/A6: U4.21 (A6), U8.18 (B1)
/A7: U4.20 (A7), U7.11 (B8)
/A8: U4.10 (A8), U6.11 (B8)
/A9: U4.9 (A9), U6.12 (B7)
/A10: U4.8 (A10), U6.13 (B6)
/A11: U4.7 (A11), U6.17 (B2)
/A12: U4.6 (A12), U5.17 (B2)
/A13: U4.5 (A13), U5.16 (B3)
/A14: U4.4 (A14), U5.15 (B4)
/A15: U4.3 (A15), U5.14 (B5)
/A16: U4.54 (A16), U5.12 (B7)
/A17: U4.19 (A17), U7.12 (B7)
/A18: U4.18 (A18), U7.13 (B6)
/A19: U4.11 (A19), U7.18 (B1)
/A20: U4.12 (A20), U7.17 (B2)
/A21: U4.15 (A21), U7.14 (B5)
/A22: U4.2 (A22), U5.13 (B6)
/A23: J2.1, J2.2, R1.2, U4.1 (A23)
/A24: J2.3, J2.4, R2.2, U4.56 (A24)
/A25: J2.5, R3.2, U4.55 (A25)
/CEA: J4.64, U9.1 (I4)
/CEB: J4.65, U9.2 (I5)
/CEC: J4.66, U9.3 (I6)
/CED: J4.67, U9.4 (I7)
/D0: U2.21 (B1), U4.35 (D0)
/D1: U2.19 (B3), U4.37 (D1)
/D2: U2.17 (B5), U4.39 (D2)
/D3: U2.15 (B7), U4.41 (D3)
/D4: U3.21 (B1), U4.44 (D4)
/D5: U3.19 (B3), U4.46 (D5)
/D6: U3.17 (B5), U4.48 (D6)
/D7: U3.15 (B7), U4.50 (D7)
/D8: U2.20 (B2), U4.36 (D8)
/D9: U2.18 (B4), U4.38 (D9)
/D10: U2.16 (B6), U4.40 (D10)
/D11: U2.14 (B8), U4.42 (D11)
/D12: U3.20 (B2), U4.45 (D12)
/D13: U3.18 (B4), U4.47 (D13)
/D14: U3.16 (B6), U4.49 (D14)
/D15: U3.14 (B8), U4.51 (A-1/D15)
/OE: U4.34 (OE), U8.12 (B7)
/ROMCE: U4.32 (CE), U6.15 (B4)
/RST: U4.14 (RESET), U7.15 (B4)
/SA0: J4.60, U8.9 (A8)
/SA1: J4.59, U8.7 (A6)
/SA2: J4.58, U8.6 (A5)
/SA3: J4.57, U8.5 (A4)
/SA4: J4.56, U8.4 (A3)
/SA5: J4.55, U8.3 (A2)
/SA6: J4.54, U8.2 (A1)
/SA7: J4.53, U7.9 (A8)
/SA8: J4.52, U6.9 (A8)
/SA9: J4.51, U6.8 (A7)
/SA10: J4.50, U6.7 (A6)
/SA11: J4.48, U6.3 (A2)
/SA12: J4.47, U5.3 (A2)
/SA13: J4.46, U5.4 (A3)
/SA14: J4.45, U5.5 (A4)
/SA15: J4.44, U5.6 (A5)
/SA16: J4.43, U5.8 (A7)
/SA17: J4.42, U7.8 (A7)
/SA18: J4.41, U7.7 (A6)
/SA19: J4.40, U7.2 (A1)
/SA20: J4.39, U7.3 (A2)
/SA21: U7.6 (A5), U9.9 (S0)
/SA22: U5.7 (A6), U9.7 (S1)
/SCE: R5.1, U2.22 (~OE), U3.22 (~OE), U6.5 (A4), U9.14 (GS)
/SD0: J4.18, U2.3 (A1)
/SD1: J4.16, U2.5 (A3)
/SD2: J4.14, U2.7 (A5)
/SD3: J4.12, U2.9 (A7)
/SD4: J4.9, U3.3 (A1)
/SD5: J4.7, U3.5 (A3)
/SD6: J4.5, U3.7 (A5)
/SD7: J4.3, U3.9 (A7)
/SD8: J4.36, U2.4 (A2)
/SD9: J4.34, U2.6 (A4)
/SD10: J4.32, U2.8 (A6)
/SD11: J4.30, U2.10 (A8)
/SD12: J4.27, U3.4 (A2)
/SD13: J4.25, U3.6 (A4)
/SD14: J4.23, U3.8 (A6)
/SD15: J4.21, U3.10 (A8)
/SOE: J4.71, U2.2 (DIR), U3.2 (DIR), U8.8 (A7)
/SRST: J4.62, U7.5 (A4)
/SWE: J4.69, U7.4 (A3)
/WE: U4.13 (WE), U7.16 (B3)
GND: C1.2, C2.2, C3.2, C4.2, C5.2, C6.2, C7.2, C8.2, C9.2, C10.2, C11.2, C12.2, C13.2, C14.2, J2.6, J4.11, J4.20, J4.29, J4.49, J4.61, J4.63, J4.68, U1.1 (GND), U2.11 (GND), U2.12 (GND), U2.13 (GND), U3.11 (GND), U3.12 (GND), U3.13 (GND), U4.33 (GND), U4.52 (GND), U5.9 (A8), U5.10 (GND), U5.19 (~OE), U6.4 (A3), U6.6 (A5), U6.10 (GND), U6.19 (~OE), U7.10 (GND), U7.19 (~OE), U8.10 (GND), U8.19 (~OE), U9.5 (EI), U9.8 (GND)
unnamed: R4.1, U9.10 (IO), U9.11 (I1), U9.12 (I2), U9.13 (I3)
VCC: C1.1, C2.1, C4.1, C6.1, C13.1, J4.1, J4.2, R4.2, R5.2, U1.3 (VI), U2.1 (V_{CCA}), U3.1 (V_{CCA}), U9.16 (VCC)
VDD: C3.1, C5.1, C7.1, C8.1, C9.1, C10.1, C11.1, C12.1, C14.1, R1.1, R2.1, R3.1, U1.2 (VO), U2.23 (V_{CCB}), U2.24 (V_{CCB}), U3.23 (V_{CCB}), U3.24 (V_{CCB}), U4.29 (VIO), U4.43 (VCC), U4.53 (RFU/BYTE), U5.1 (DIR), U5.2 (A1), U5.20 (VCC), U6.1 (DIR), U6.2 (A1), U6.20 (VCC), U7.1 (DIR), U7.20 (VCC), U8.1 (DIR), U8.20 (VCC)

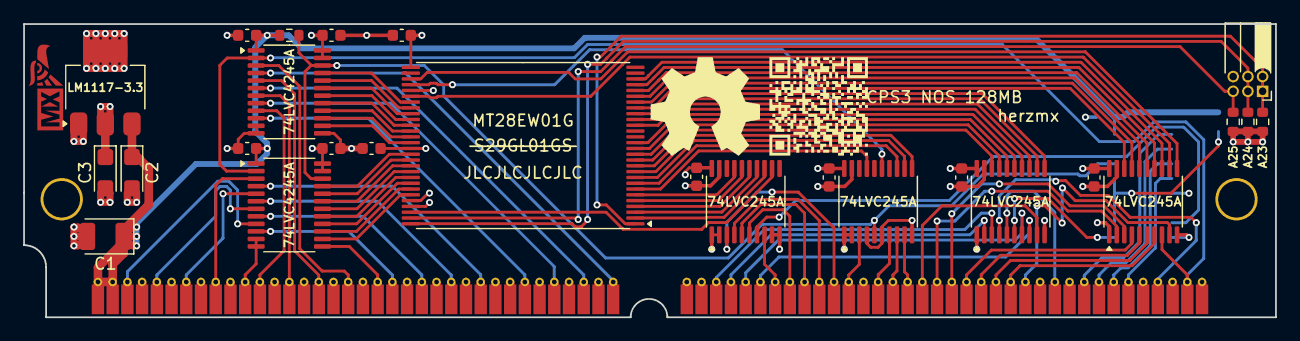
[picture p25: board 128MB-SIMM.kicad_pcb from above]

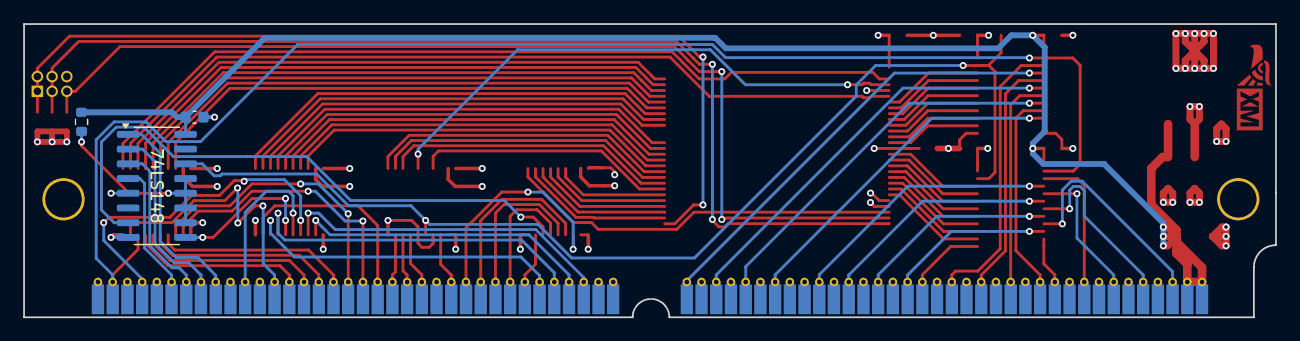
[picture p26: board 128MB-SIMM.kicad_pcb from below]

Board: 4 copper layers, 108.0 x 25.3 mm, 30 parts (4 on the bottom side), 97 nets.

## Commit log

2022-12-05 Create 64MB project
    [64MB-SIMM.kicad_pcb, 64MB-SIMM.kicad_sch]
2022-12-05 Create 128MB project
    [128MB-SIMM.kicad_pcb, 128MB-SIMM.kicad_sch]
2024-12-06 Updated symbols and added footprints
2024-12-06 Updated 128 SIMM for release
    [128MB-SIMM.kicad_pcb, 128MB-SIMM.kicad_sch]
2024-12-06 Updated 64 SIMM for release
    [64MB-SIMM.kicad_pcb, 64MB-SIMM.kicad_sch]
2024-12-06 Added SIMM SW to bank switch
    [SIMM-SWITCH.kicad_pcb, SIMM-SWITCH.kicad_sch]
2024-12-06 move src files
    [128MB-SIMM.kicad_pcb, 128MB-SIMM.kicad_sch, 64MB-SIMM.kicad_pcb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]
2024-12-06 Updated footprints
    [SIMM-SWITCH.kicad_pcb, SIMM-SWITCH.kicad_sch, SW-SMD_6P-L7.6-W6.1-H4.2-P2.54-LS9.8.step]
2024-12-06 update sw for release
    [SIMM-SWITCH.kicad_pcb, SIMM-SWITCH.kicad_sch]
2025-01-07 Update README 1.2mm tickness PCB
2025-01-07 add missing hw files
    [128MB-SIMM-BOM.csv, 64MB-SIMM-BOM.csv, CPS3-SIMM-SW-BOM.csv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]
